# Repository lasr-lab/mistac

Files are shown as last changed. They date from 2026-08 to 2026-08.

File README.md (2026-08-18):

# MISTac  



<div style="max-width: 850px; margin: 0 auto; text-align: center;">

  <a href="https://arxiv.org/abs/2608.14772">
    <strong>MISTac: A Vision-Based Tactile Sensor for Minimally Invasive Surgery</strong>
  </a>
  <br>
  <em>Robin Koch, Anabella Mascot, Rayan Younis,<br>  Martin Wagner, Stefanie Speidel, Marc Cutkosky, Ingo Sieber, and Roberto Calandra</em>

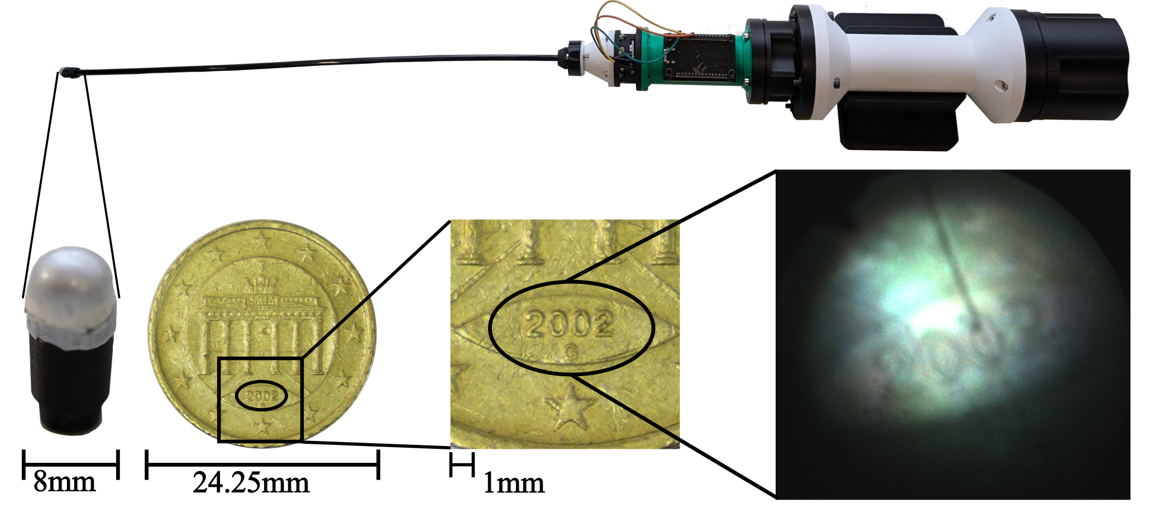
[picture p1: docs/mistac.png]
MISTac


  <div style="text-align: left; margin-top: 1rem;">
    MISTac is a vision-based tactile sensor designed for use during minimally invasive surgery (MIS). It features a replaceable 8mm sensor tip that is compatible with the trocars used in MIS.
    A fiber optic bundle allows the use of bulky off-the-shelf components at the proximal end of the sensor. The sensor housing is fully modular for easy repairs and upgrades.
  </div>

</div>

## Content
This repository contains the CAD files and BOM for manufacturing the proximal and distal end of the MISTac vision-based tactile sensor, as well as the code used to set its illumination. <br> 
**Full build guide coming soon.**

## Citing
If you use this project in your research, please cite this [paper](https://arxiv.org/abs/2608.14772):
```
@misc{koch2026mistac,
      title={MISTac: A Vision-Based Tactile Sensor for Minimally Invasive Surgery}, 
      author={Robin Koch and Annabella Mascot and Rayan Younis and Martin Wagner and Stefanie Speidel and Mark Cutkosky and Ingo Sieber and Roberto Calandra},
      year={2026},
      eprint={2608.14772},
      archivePrefix={arXiv},
      primaryClass={cs.RO},
      url={https://arxiv.org/abs/2608.14772}, 
}
```
## License
These design files are licensed under CC-by-NC-SA, as found in the [LICENSE](LICENSE) file.

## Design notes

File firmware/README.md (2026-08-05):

# Illumination System - Controlling LEDs
Code to set the LEDs of the NeoPixel Ring in the MISTac. The LED color and brightness as well as their illumination type can be set via a python script running on a host PC. There are two illumination types available: static illumination in which the colors stay the same and dynamic illumination in which the LEDs can be set to loop through a cycle. The last LED settings are stored on the MCU and are reloaded whenever the MCU is connected to power, so the LEDs don't have to be re-set everytime the MCU is reconnected to power.

## Flashing c++ code onto the ESP32 MCU
The c++ code is flashed onto the ESP32dev board using [platformio](https://platformio.org/). 

## Setting LEDs
An example for both LED settings is provided in ```example.py```.

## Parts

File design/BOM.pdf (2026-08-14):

Part Name | Subassembly | Description | Quantity | Material
fiberHolderCase1 | Fiber Holder | | 1 | PLA
fiberFixationBracketOuter | Fiber Holder | | 2 | PLA
fiberHolderCase1 | Fiber Holder | | 1 | PLA
adjustmentMechanismMiddle | Fiber Holder | | 1 | PLA
adjustmentMechanismConnectorFiberHolder | Fiber Holder | | 1 | PLA
adjustmentMechanismConnectorObjective | Fiber Holder | | 1 | PLA
centeringDisk | Fiber Holder | | 1 | TPU
fiberFixationBracketInner | Fiber Holder | | 2 | TPU
Component1 | Fiber Holder | component of fiberFixationBracketInner | 2 | TPU
Component2 | Fiber Holder | component of fiberFixationBracketInner | 2 | TPU
espHolder | | | 1 | PLA
ledHolder | Collimator | | 1 | PLA
illuminationFiberGuide | Collimator | | 1 | PLA
illumination_guide_inner_shell | Collimator | component of IlluminationFiberGuide | 1 | PLA
illumination_guide_outer_shell | Collimator | component of IlluminationFiberGuide | 1 | PLA
fiberFrictionFastener | Collimator | | 1 | TPU
camearaHolderCamera | CamearHolder | | 1 | PLA
cameraHolderConnectorEyepiece | CamearHolder | | 1 | PLA
cameraHolderMiddle | CamearHolder | | 1 | PLA
microscopeHolderMain | MicroscopeHolder | | 1 | PLA
fasteningNut | MicroscopeHolder | | 1 | PLA
RMSThreadInsert | MicroscopeHolder | | 1 | PLA
moldCartrdigeHolder | Mold | 1 | PLA
moldHolder | Mold | 1 | PLA
moldSensorTip | Mold | 1 | ASA
cartridgeUndercut | Distal End | 2 | PLA
cartridgeInnerMesh | Distal End | 2 | PLA
squeezeRing | Distal End | 1 | TPU
fasteningNutTip | Distal End | 1 | PLA

MeditFiberscope

Product discontinued, in contact with
manufacturer for replacement options | 1 | NA
Esp32 dev module | Fiber Holder | Link: https://de.aliexpress.com/item/1005009773468597.html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 1 | NA
cables - AWG 24 - 120mm length | NA | Link: https://www.berrybase.de/flachkabel-bunt-rm-1-4mm-10pin-awg-24?number=FK10B24-10 3 | NA
NeopixelRing 8 LEDs | Collimator | Link: https://www.berrybase.de/neopixel-ring-mit-8-ws2812-5050-rgb-leds 1 | NA
USB Camera - DFM 37UX568-ML | CamearHolder | Link: https://www.theimagingsource.com/en-us/product/board/37u/dmm37ux568ml/ 1 | NA
Dupont Crimp connectors | | Link: https://www.berrybase.de/610-teiliges-dupont-crimp-steckverbinder-set-in-kunststoffbox 3 | NA
USB C Cable | | Link: https://www.amazon.de/-/en/AmazonBasics-USB-Type-C-2-0-Cable-black/dp/B01GGKZ1VA?th=1 2 | NA
Microscope Objective - Kern OBB-A1238 | | Link: https://kern-fachhandel.de/produkt/kern-objektiv-10-x-plan-achromatisch-obb-a1238/ 1 | NA
Microscope Eypiece - Kern OBB-A3200 | | Link: https://kern-fachhandel.de/produkt/kern-okular-wf-10-x-o-18-mm-anti-fungus-obb-a3200/ 1 | NA
Hexagon Nut - M4 x 0.7 | | 8 | NA
Hexagon Socket Head Cap Screw - M2 x 0.4 x 12 | | 12 | NA
Hexagon Socket Head Cap Screw - M4 x 0.7 x 25 | | 8 | NA
Hexagon Nut - M3 x 0.5 | | 12 | NA
Hexagon Socket Head Cap Screw - M3 x 0.5 x 30 | | 4 | NA
Hexagon Socket Head Cap Screw - M3 x 0.5 x 10 | | 4 | NA
Hexagon Nut - M2 x 0.4 | | 12 | NA
Hexagon Socket Head Cap Screw - M2 x 0.4 | | 4 | NA
Hexagon Socket Head Cap Screw - M3 x 0.5 x 16 | | 4 | NA
Heat inserts - M2 | | 4 | NA
Hexagon Socket Head Cap Screw - M2 x 0.4 x 8 | | 4 | NA
ASA filament | Link: https://www.material4print.de/filament/asa/4/asa-tiefschwarz?c=16 1 | | NA

Proximal End

Distal End

3rd Party Materials

Consumable Items

PLA filament | Link: https://www.material4print.de/filament/pla/1/pla-tiefschwarz?c=7 2 | | NA
TPU filament | Link: https://www.3djake.de/esun/etpu-95a-black | 1 | NA
Silicone Addition Clear 5A | Link: https://siliconesandmore.com/en/products/silicone-addition-clear-5-very-soft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 1 | | NA
Cast Magic Silver Bullet | Link: https://www.kaupo.de/shop/en/URETHANE-Accessories/CAST-MAGIC-POWDERS/Silver-Bullet-1.html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 1 | | NA
Ecolfex 00-10 | Link: https://www.kaupo.de/shop/en/SILICONE-RUBBER-Platinum-Cure/ECOFLEX-SERIES/Ecoflex-00-10/ECO-FLEX-0010-1-Silicone-Rubber.html 1 | | NA
Paper/plastic cups | | 10 or more | NA
Scotch tape | | 1 | NA
Dish soap | | 1 | NA
Nitrile gloves | | 10 or more | NA
Paper towels | | | NA
Wooden spatula | Link: https://www.amazon.de/-/en/%C3%96kolution-Stirrers-Sustainable-Environmentally-Packaging/dp/B0B7BVH75Q/ 100 or more | | NA
Acetone | Link: https://de.rs-online.com/web/p/elektronik-reiniger/9185046?gb=s 1 | | NA
Vaccum pump | Link: https://vacuumchambers.eu/en_US/p/Set-for-wood-stabilizing-chamber-20.0l-VC3028AG-pump-170lmin-VP260/64 1 | | NA
3D printer | | 1 | NA
Scale | Link: https://www.kern-fachhandel.de/produkt/schulwaage-emb-1000-2-waegebereich-1000-g-ablesbarkeit-001-g/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 1 | | NA
Acetone Vapor Chamber | e.g.: https://www.smith3d.com/complete-guide-to-3d-print-smoothing-acetone-vapor-bath-safety-techniques/ 1 | | NA
Syringe (optional) | https://www.carlroth.com/de/de/einmalspritzen/einmalspritze-omnifix-mit-luer-lock-anschluss/p/t552.2 10 or more | | NA
Scalpel (optional) | | | NA
Tweezers | | 1 | NA

Tools

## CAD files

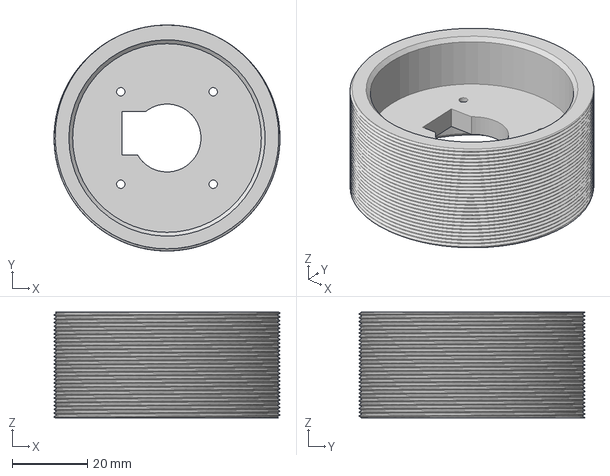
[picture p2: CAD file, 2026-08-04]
design/proximalEnd/microscopeHolder/microscopeHolderMain.step
59.9 x 59.9 x 28.0 mm

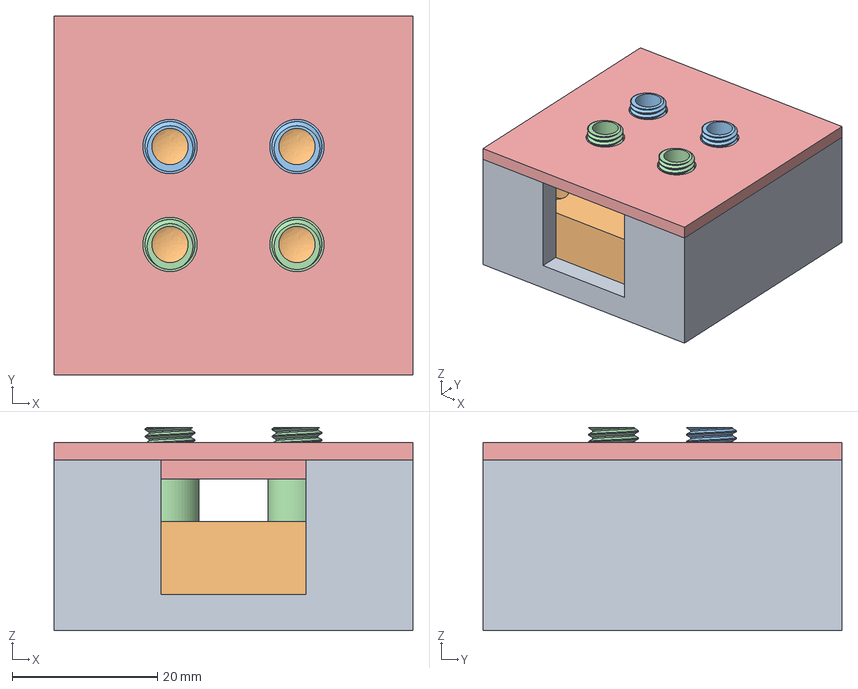
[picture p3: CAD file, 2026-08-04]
design/distalEnd/assemblyMISTacMold.step
49.5 x 49.5 x 28.0 mm
moldHolder
moldSensorTip
cartridgeUndercut x 2
cartridgeInnerMesh x 2
moldCartrdigeHolder

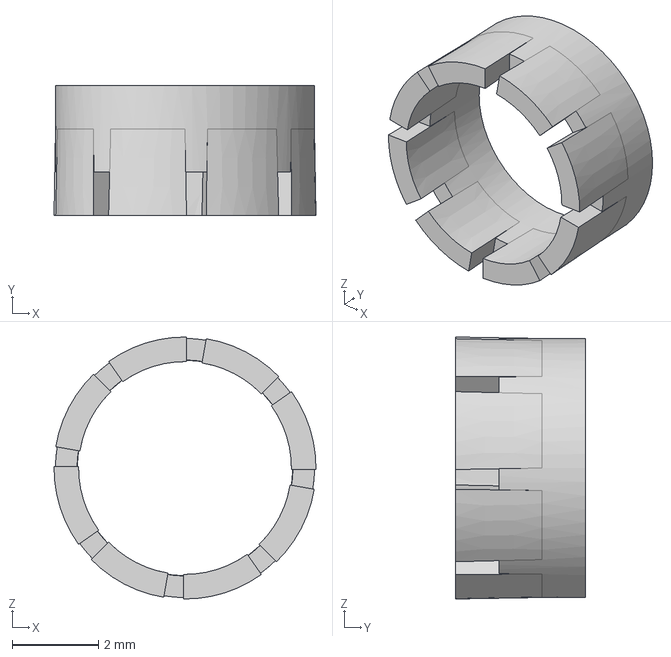
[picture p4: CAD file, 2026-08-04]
design/distalEnd/squeezeRing.step
6.07 x 3.00 x 6.07 mm

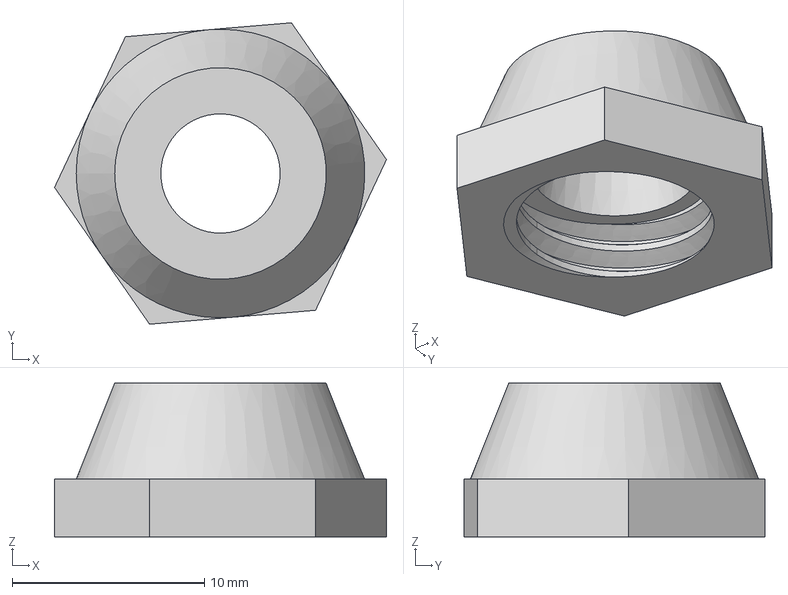
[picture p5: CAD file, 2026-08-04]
design/proximalEnd/collimator/fasteningNut.step
17.3 x 15.7 x 8.00 mm

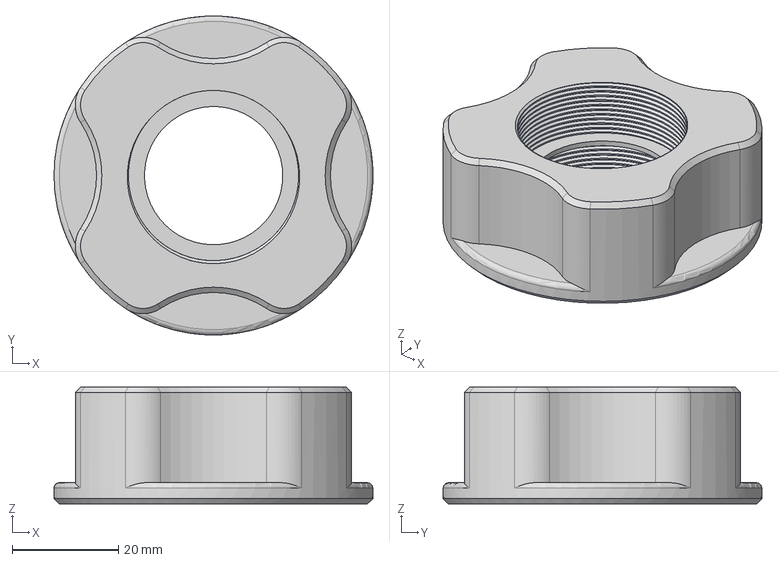
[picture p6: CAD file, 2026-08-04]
design/proximalEnd/fiberHolder/adjustmentMechanismMiddle.step
60.0 x 60.0 x 22.0 mm

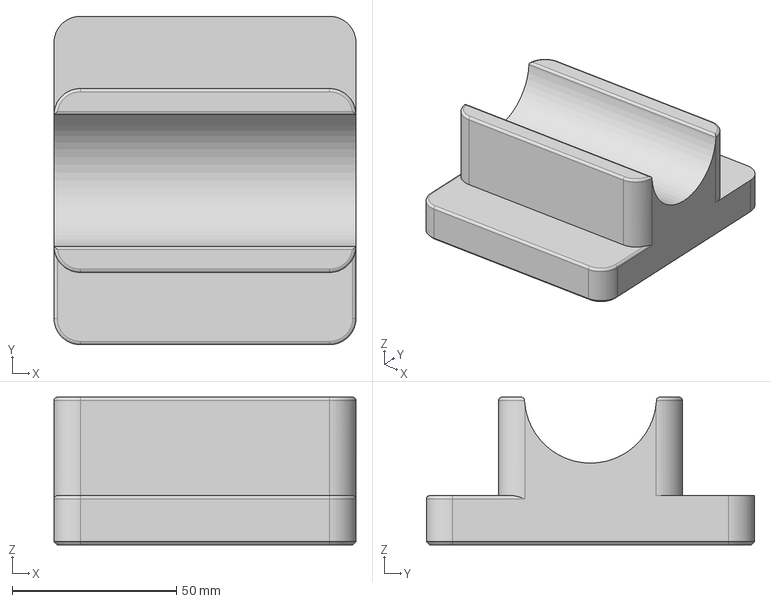
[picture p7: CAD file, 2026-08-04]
design/proximalEnd/sensor_holder.step
92.0 x 100.0 x 45.0 mm

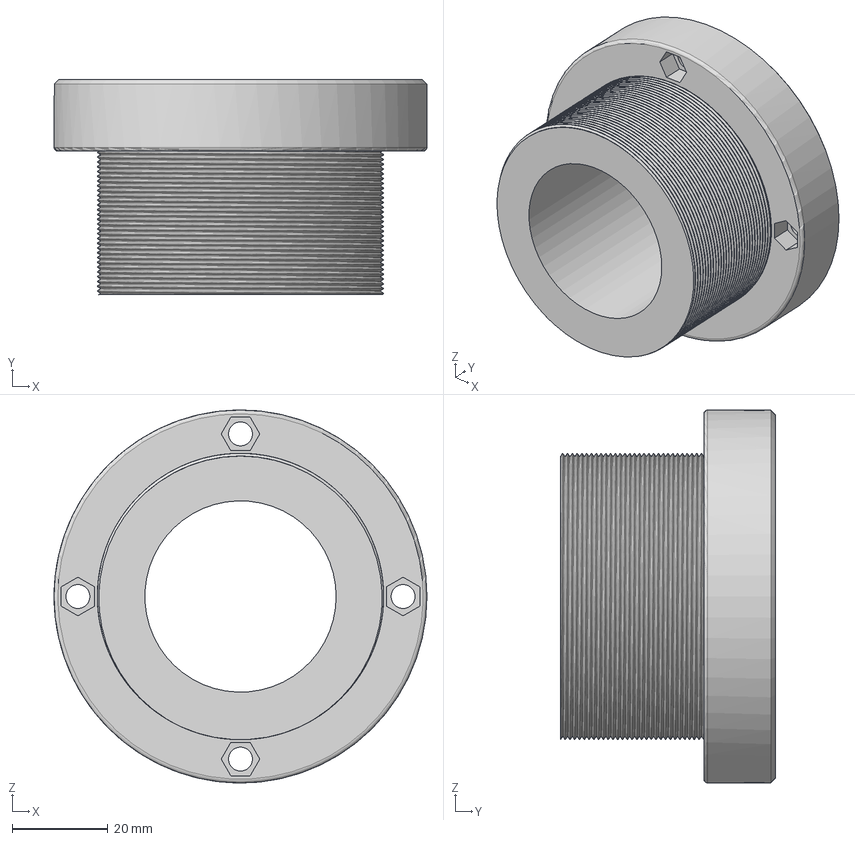
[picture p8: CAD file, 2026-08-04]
design/proximalEnd/cameraHolder/cameraHolderConnectorEyepiece.step
78.0 x 45.0 x 78.0 mm

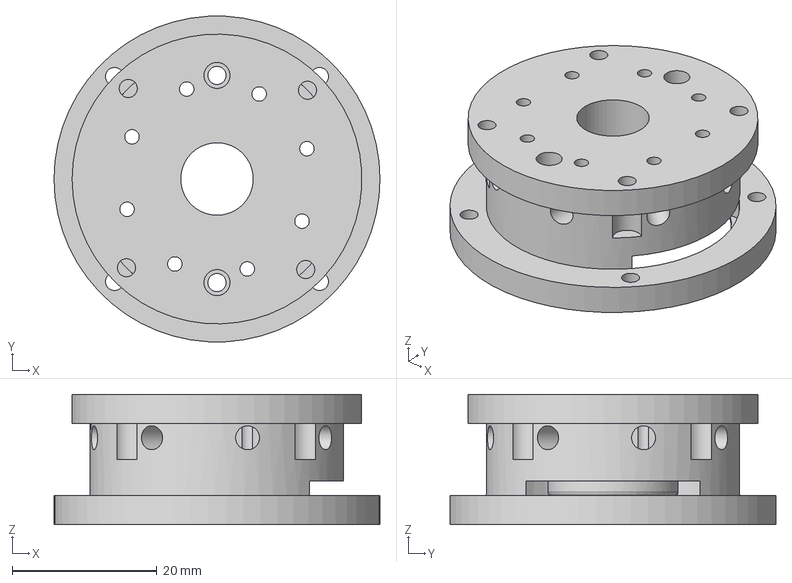
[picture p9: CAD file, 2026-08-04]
design/proximalEnd/collimator/ledHolder.step
45.0 x 44.9 x 18.0 mm

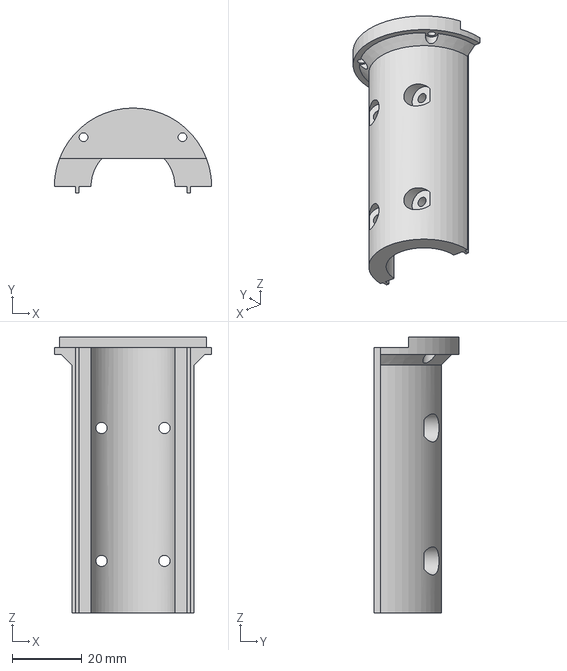
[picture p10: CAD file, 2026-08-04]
design/proximalEnd/fiberHolder/fiberHolderCase2.step
45.0 x 24.3 x 78.9 mm

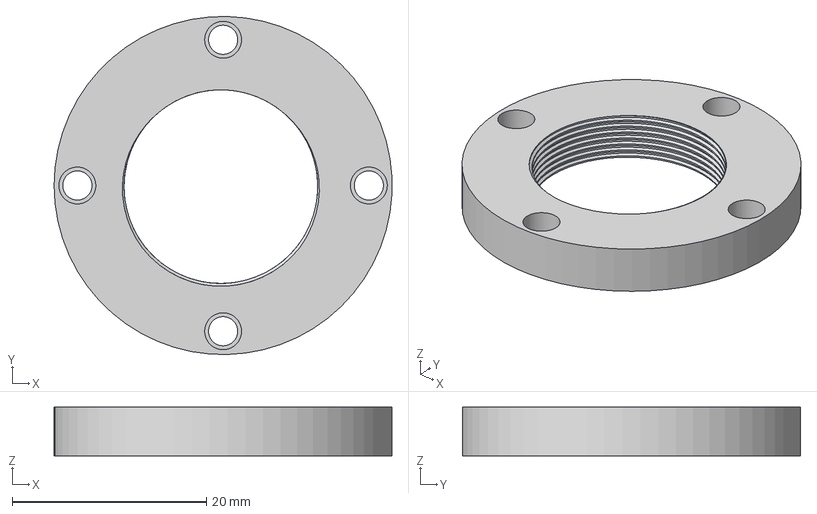
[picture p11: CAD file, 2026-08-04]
design/proximalEnd/microscopeHolder/RMSThreadInsert.step
34.8 x 34.8 x 5.00 mm

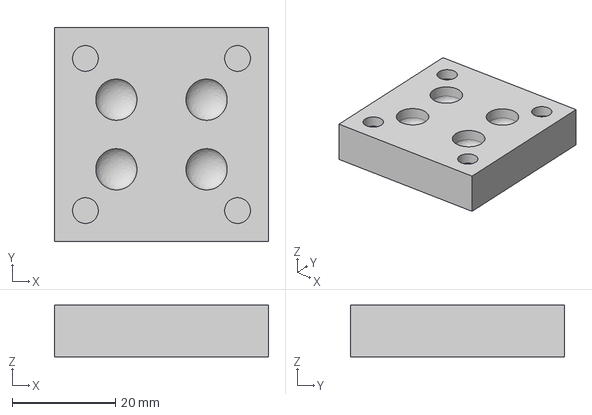
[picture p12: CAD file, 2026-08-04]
design/distalEnd/moldSensorTip.step
41.5 x 41.5 x 10.0 mm

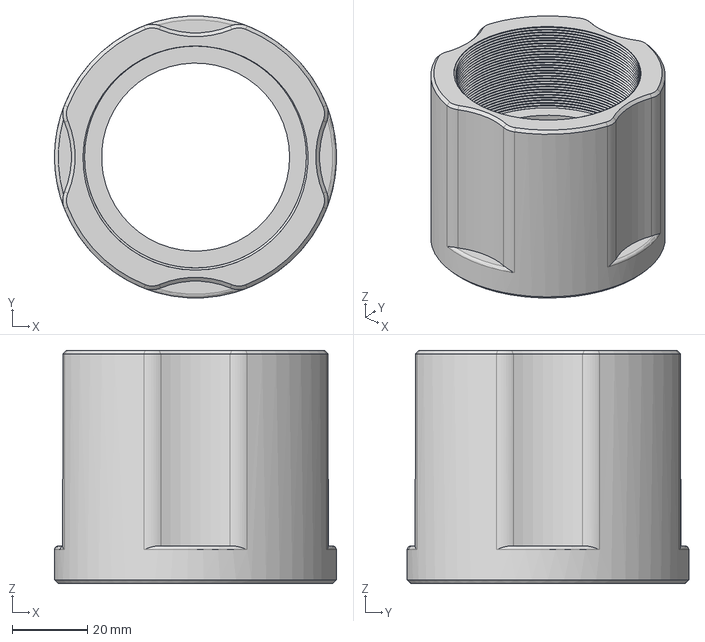
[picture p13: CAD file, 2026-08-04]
design/proximalEnd/cameraHolder/cameraHolderMiddle.step
75.0 x 74.9 x 62.0 mm

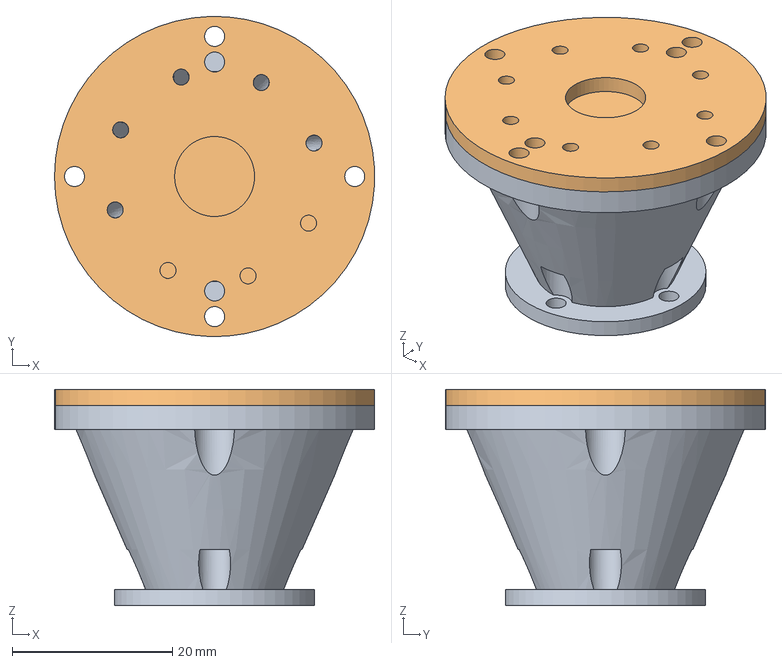
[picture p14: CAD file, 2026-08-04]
design/proximalEnd/collimator/illuminationFiberGuide.step
40.0 x 40.0 x 27.0 mm

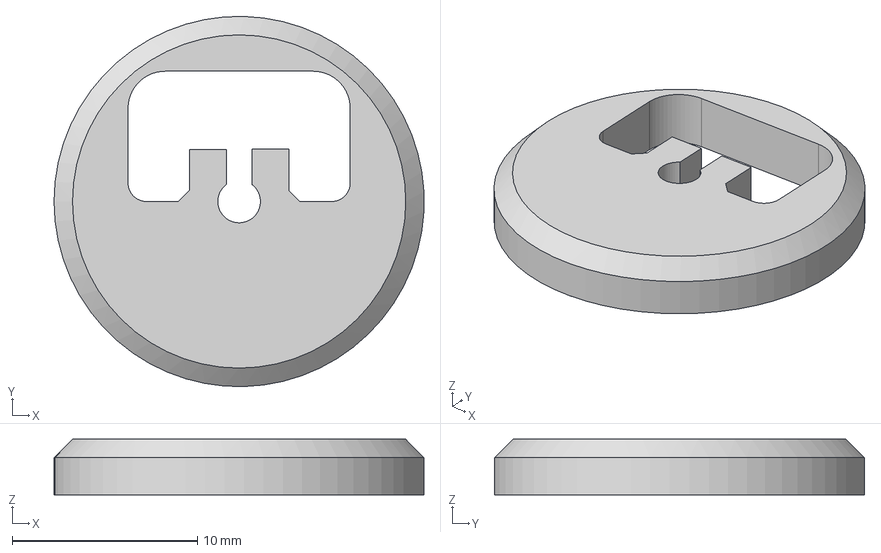
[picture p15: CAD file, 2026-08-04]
design/proximalEnd/fiberHolder/centerDisk.step
20.0 x 20.0 x 3.00 mm

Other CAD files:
design/proximalEnd/cameraHolder/camearaHolderCamera.step
design/distalEnd/cartridgeInnerMesh.step
design/proximalEnd/collimator/fiberFrictionFastener.step
design/proximalEnd/fiberHolder/fiberHolderCase1.step
design/distalEnd/cartridgeUndercut.step
design/distalEnd/fasteningNutTip.step
design/distalEnd/moldCartrdigeHolder.step
design/distalEnd/moldHolder.step
design/proximalEnd/fiberHolder/adjustmentMechanismConnectorFiberHolder.step
design/proximalEnd/fiberHolder/adjustmentMechanismConnectorObjective.step
design/proximalEnd/fiberHolder/espHolder.step
design/proximalEnd/fiberHolder/fiberFixationBracketInner.step
design/proximalEnd/fiberHolder/fiberFixationBracketOuter.step

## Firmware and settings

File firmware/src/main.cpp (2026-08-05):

#include <vector>
#include <sstream>

#include <Arduino.h>
#include "pixel_ring.h"

using std::string;
using std::vector;

#define TIMEOUT 5000

PixelRing pixel_ring;
HardwareSerial* serial;

void setup() {
    pixel_ring.begin();
    serial = &pixel_ring.serial.hw_serial;
    serial->println("Setup finished");
}

unsigned long last_received_time=0;
void loop() {
    //delay(1000);
    if (serial->available()) {
        string line = pixel_ring.serial.read_line();
        // read_line returns an empty string for garbage on the line, only a
        // complete command counts as serial communication
        if (!line.empty()) {
            pixel_ring.serial.print_err("taking commands");
            pixel_ring.set_use_stored_settings(false);
            pixel_ring.handle_command(line);
            last_received_time = millis(); // Reset timeout timer
        }
    }
    // If no serial communication for TIMEOUT ms, revert to stored settings
    if (millis()-last_received_time > TIMEOUT && !pixel_ring.get_use_stored_settings()) {
        pixel_ring.serial.print_err("loading_stored");
        pixel_ring.load_stored_led_settings(pixel_ring.get_preferences(),pixel_ring.get_led_map());
        pixel_ring.set_use_stored_settings(true);
    }
  // If dynamic mode is active, the leds are updated, if not nothing happens
  pixel_ring.update_dynamic_leds();
   
}

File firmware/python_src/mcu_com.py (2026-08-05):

import serial
import struct
import threading
import typing


class MCUcom:

    def __init__(self, port: str | None, baudrate: int, timeout: float | None=None) -> None:
        self._mcu_serial = serial.Serial(port, baudrate, timeout=timeout)

    
    def open(self) -> None:
        self._mcu_serial.open()

    
    def is_open(self) -> bool:
        return self.is_open

    
    def close(self) -> None:
        self._mcu_serial.close()


    def is_open(self) -> bool:
        return self._mcu_serial.is_open


    def available(self) -> int:
        return self._mcu_serial.in_waiting


    def read(self, size: int = 1) -> bytes:
        received = self._mcu_serial.read(size)
        if len(received) < size:
            raise TimeoutError(f"Tried to read {size} bytes, but only received {len(received)} bytes containing {received}")
        return received


    def read_all(self) -> bytes | None:
        return self._mcu_serial.read_all()


    def readline(self) -> bytes:
        response = self._mcu_serial.readline()
        if len(response) == 0:
            raise TimeoutError("Did not get response from ESP32 in time")
        if not chr(response[-1]) == '\n':
            raise TimeoutError(f"Did not read full line from ESP32 in time. Response was: {response}")
        return response


    def readline_monitor(self) -> None:     # TODO add threading.Event
        while True:
            if self.available():
                response = self.readline()
                print(response);


    def printline(self, string: str) -> None:
        print(string)
        try:
            b_written =self._mcu_serial.write((string+'\n').encode('utf-8'))
            print(f'wrote {b_written} bytes')
        except Exception as e:
            print(e)
        
        self._mcu_serial.flush()




if __name__ == "__main__":
    mcu_com = MCUcom()

    mcu_monitor = threading.Thread(target=mcu_com.readline_monitor)
    mcu_monitor.start();
    
    while True:
        print('com is running')
        inp = input()
        if inp[0].upper() in ['S', 'D']:
            mcu_com.printline(inp)
        else:
            print(f"{inp[0]} not recognized, command hasn't been sent to ESP32")

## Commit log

2026-08-06 update BOM
2026-08-17 improve README, rename files and directories
    [RMSThreadInsert.step, adjustmentMechanismConnectorFiberHolder.step, adjustmentMechanismConnectorObjective.step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]

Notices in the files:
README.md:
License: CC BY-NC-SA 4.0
